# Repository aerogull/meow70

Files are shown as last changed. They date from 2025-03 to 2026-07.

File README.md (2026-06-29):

# Meow70
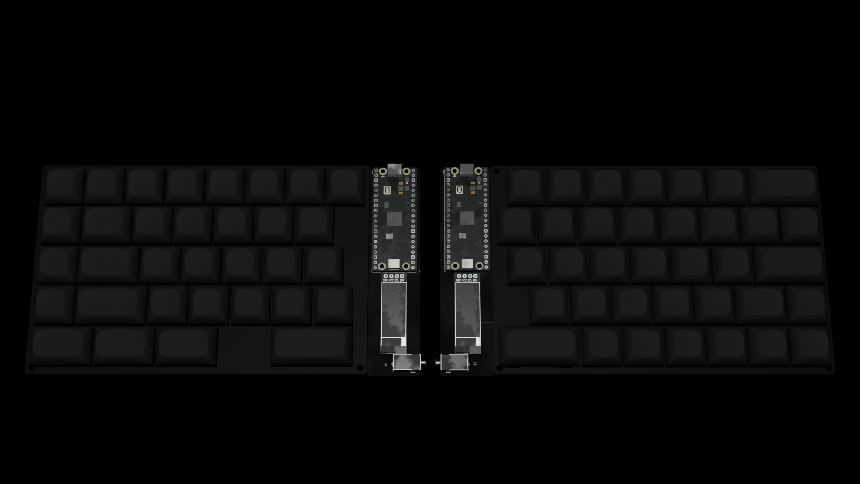
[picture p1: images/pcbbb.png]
render


## Building the Board
My idea started with how I wanted a split keyboard that wasn't ortholinear or ergo. So, I took a picture of my Keychron K6 Pro, and designed a split keyboard off of it. It runs on 2 Raspberry Pi Picos (or drop in replacements) with a simple, open case design and qmk firmware.\
This was a pretty difficult build, I ended up redoing the routing and placement several times, going from a staggered edge with the controllers mounted underneath, to what I have today. The most difficult part was doing the render of the keyboard (which is still a WIP, this is just temporary). My KICAD always gave me destroyed meshes that would take hours to import into any software. Once I finally got something imported, it took me 2 days of constantly doing little things and saving my work before blender crashed. The final render took over 8 minutes to finish, so it was quite an undertaking getting it to work.

## Bill of Materials
* 1x set of pcbs
* 2x Raspberry Pi Pico H
* 69x Kailh Hotswap Sockets (MX Style)
* 69x 1N4148 Diodes
* 69x MX-Style Switches
* 4x Plate-Mounted Stabilizers
* 2x 0.91" I2C PCB-Mounted OLED Displays
* 2x TRRS Audio Jack Connectors
* 8x M3 Screws
* 8x M3 Heatset Inserts

## More Photos
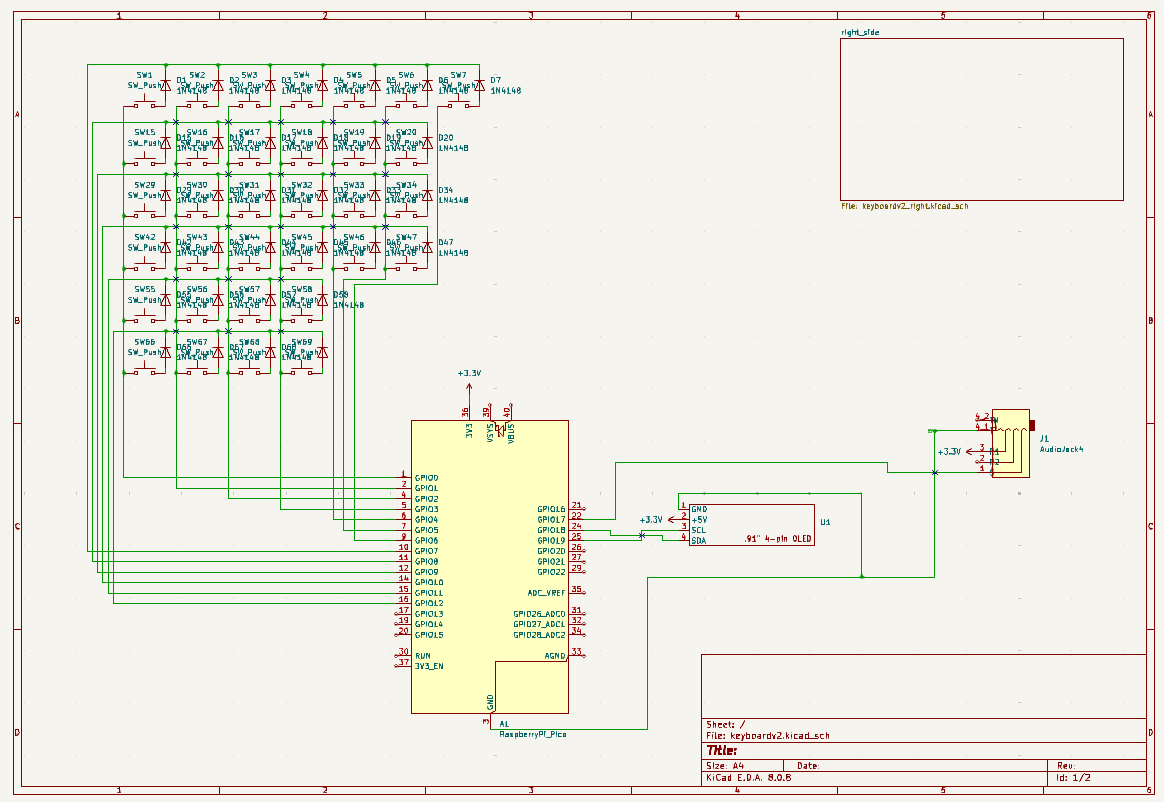
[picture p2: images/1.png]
schematic

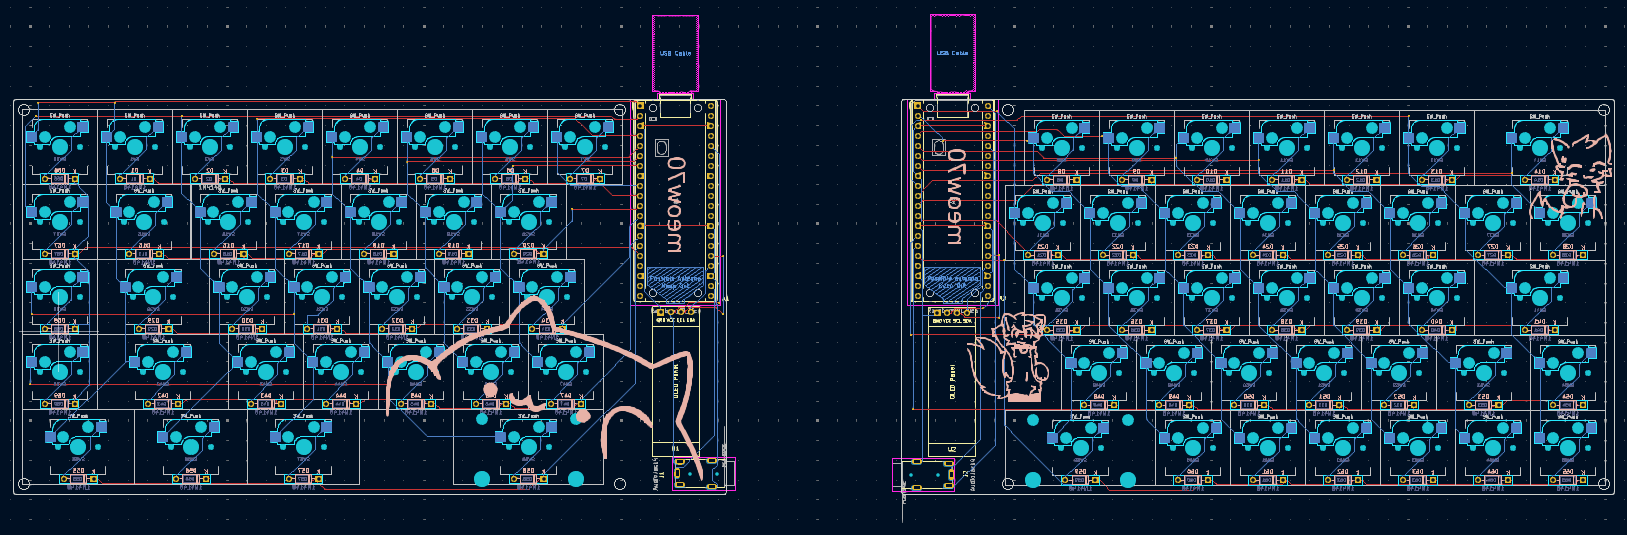
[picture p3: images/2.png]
pcb

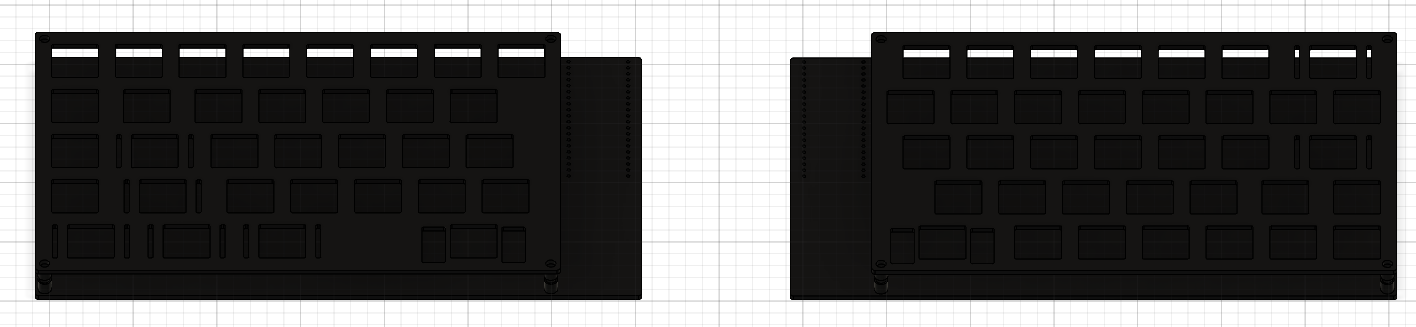
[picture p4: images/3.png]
case


## KICAD BOM (with prices for what I used)
|Quantity|Item|Designation|Price Each|Total Price + Shipping|Link|
|----|----|----|----|----|----|
|69|"MX-Hotswap"|"SW_Push"|$0.138|$9.65|[here](https://www.aliexpress.us/item/3256807039037559.html)|
|2|"RaspberryPi_Pico_Common_THT_wModel"|"RaspberryPi_Pico"|$4|Provided by HackClub HQ!||
|2|"SSD1306-0.91-OLED-4pin-128x32"|"~"|$1.845|$3.69|[here](https://www.aliexpress.us/item/3256805967573053.html)|
|2|"TENSILITY_54-00174" (PJ-332)|"AudioJack4"|$0.234|$2.34|[here](https://www.aliexpress.us/item/3256807580272301.html)|
|69|"D_DO-35_SOD27_P7.62mm_Horizontal"|"1N4148"|$0.0174|$1.74|[here](https://www.aliexpress.us/item/3256806058794623.html)|
|69|MX Mechanical Switches|Gateron G Pro 3.0 Silvers|$0.345|$50.11|[here](https://www.gateron.co/products/gateron-g-pro-3-0-switch-set?variant=40479583043673)
|69|Keycaps|3D Printed (Cherry or DSA)|Printing Legion||[this](https://github.com/rsheldiii/KeyV2) or [this](https://github.com/anhthang/dsa-keycap)|
|8|Heatset Inserts|97164A112|$0.0574|$5.74|[here](https://www.aliexpress.us/item/3256805603102147.html)|
|4|Stabilizers|Gateron 2u Stabs|$2.547|$15.28|[here](https://www.aliexpress.us/item/3256805212136654.html)|
|1|TRRS Cable|Random Aliexpress Coiled TRRS Cable|$6.94|$6.94|[here](https://www.aliexpress.us/item/3256806811164725.html)|
|1|Full Case|4 Parts Split Up for Printing|Self or Printing Legion||[here](https://github.com/aerogull/meow70/tree/main/prod)|
|8|Screws|3mm 0.5x16mm|$0.345|$2.76|[here](https://www.lowes.com/pd/Hillman-3mm-0-5-x-16mm-Allen-Drive-Cap-Screws-4-Count/50088880)|
|5|Sets of PCBs|JLCPCB|$20.70 (for 5)|$55.95|[here](https://cart.jlcpcb.com/quote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)|

[link to step model of completed board](https://hc-cdn.hel1.your-objectstorage.com/s/v3/b98df7d8c57167f14ca20340c5cecc1c217099e2_full_assembly_para.step)

## Completed Build!
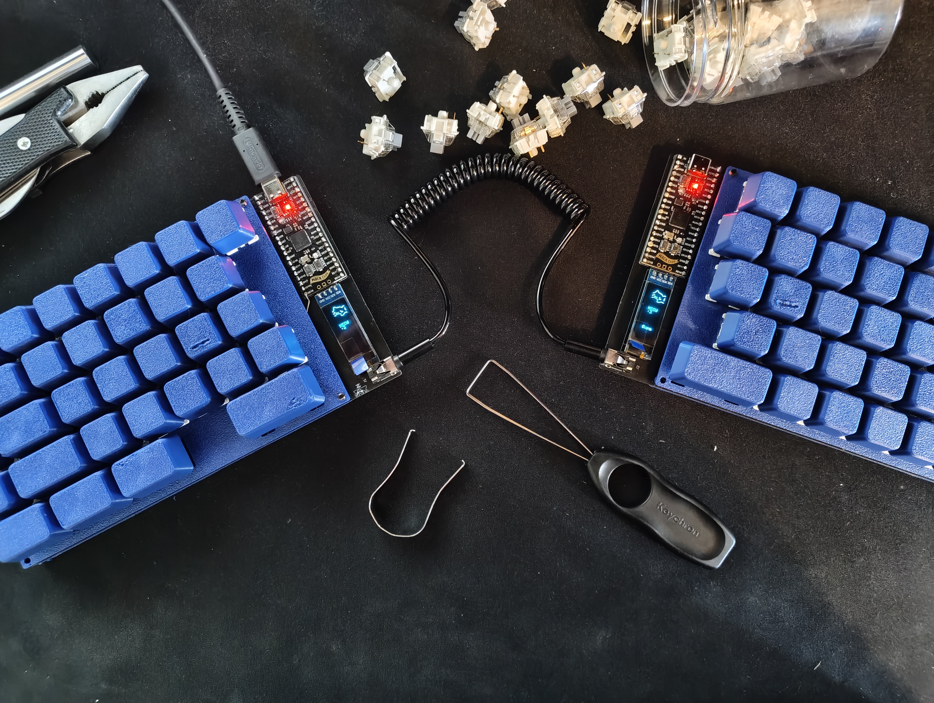
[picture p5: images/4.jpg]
build


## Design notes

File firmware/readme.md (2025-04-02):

# meow70

meow70

*A short description of the keyboard/project*

* Keyboard Maintainer: [aerogull](https://github.com/aerogull)
* Hardware Supported: the meow70 project
* Hardware Availability: *Links to where you can find this hardware*

Make example for this keyboard (after setting up your build environment):

    make meow70:default

Flashing example for this keyboard:

    make meow70:default:flash

See the [build environment setup](https://docs.qmk.fm/#/getting_started_build_tools) and the [make instructions](https://docs.qmk.fm/#/getting_started_make_guide) for more information. Brand new to QMK? Start with our [Complete Newbs Guide](https://docs.qmk.fm/#/newbs).

## Bootloader

Enter the bootloader in 3 ways:

* **Bootmagic reset**: Hold down the key at (0,0) in the matrix (usually the top left key or Escape) and plug in the keyboard
* **Physical reset button**: Briefly press the button on the back of the PCB - some may have pads you must short instead
* **Keycode in layout**: Press the key mapped to `QK_BOOT` if it is available

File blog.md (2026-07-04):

This a split keyboard that maintains most of the traditional layout of a standard keyboard.

69 total keys (nice)

4 programmable buttons (hardware macros :3)

2 layer switch buttons for even more keys (mmmmm function row)

USB-C connectivity (orph picos my beloved)

Dynamic master/slave (double the connectivity) 

TRRS cable connections (very sproingey)

2 128x32 OLED displays (2xBongo Cats not included)

Built in QMK (low latency for all the gamin)

VIA support (yk, unofficially)

Simple pcb shape (for making many many cases)

Hotswap keys (i'm thinking linears today, tactiles tomorrow)

Preconfigured out-of-the-box (some eeprom flashing required)

Everything was done by me, @aerogull.

Schematic:
    In the schematic, I set up the basics for how the keyboard functions, outlining serial communication between the halves, setting up matricies, and i2c communication for the displays. Each key also has it's own diode to prevent ghost taps and other crosstalk. I chose to use a pair of raspberry picos because of the amount of copycat footprints that could be used for drop in replacement boards.

PCB Design:
    This was where the layout really mattered. I wanted to copy my existing keyboard, a keychron 60 percent, but make it split for easier transport and travel use. The macro keys were placed on the sides to help mirror the shape of the keyboard halves, allowing for more uniform cases and designs. 

Case:
    I went with a really simple and open layout for 2 reasons, I like the sound better, and I did not have an easy way to prototype test tolerences and fit. It was originally designed to be used with heatset inserts, but it ended up being easier to drive the screws directly into the plastic. The plate was made with ai03 plate-gen, but the mounts for the stabs are the wrong kind so I had to dremel away some material to make them fit.

Firmware:
    QMK, pretty simple design with all the display hardcoded and eeprom flashing so you can't mess up where you plug the cord in. This firmware was developed in about 2 days or work, split across several years, so it went through some drastic changes. NKRO is enabled by default, and has unofficial via support included.

Render:
    Yay, blender! This was a lot of work trying to figure out why my mesh was in the GBs and why everything was a blog, but I think it turned out pretty good.

Build:
    I uh, didn't have any microcontroller headers, and broke one of the hotswap sockets that I only had one spare for so, it went about as good as it could go. It took about 9 hours of work to put it all together and get firmware tested and bug fixed.

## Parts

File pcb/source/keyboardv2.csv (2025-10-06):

Id | Designator | Footprint | Quantity | Designation | Supplier and ref
1 | SW17,SW20,SW24,SW3,SW67,SW47,SW49,SW2,SW62,SW52,SW44,SW11,SW40,SW9,SW1,SW64,SW50,SW39,SW51,SW60,SW34,SW36,SW37,SW38,SW10,SW28,SW16,SW35,SW19,SW32,SW27,SW7,SW21,SW68,SW66,SW25,SW45,SW69,SW23,SW26,SW13,SW65,SW22,SW8,SW54,SW63,SW18,SW5,SW46,SW43,SW30,SW61,SW31,SW4,SW6,SW33,SW48,SW12 | MX-Hotswap-1U | 58 | SW_Push
2 | SW53,SW15 | MX-Hotswap-1.25U | 2 | SW_Push
3 | A1,A3 | RaspberryPi_Pico_Common_THT_wModel | 2 | RaspberryPi_Pico
4 | SW42,SW14,SW41 | MX-Hotswap-1.75U | 3 | SW_Push
5 | U2,U1 | SSD1306-0.91-OLED-4pin-128x32 | 2 | ~
6 | SW56,SW29,SW57,SW55 | MX-Hotswap-1.5U | 4 | SW_Push
7 | J2,J1 | TENSILITY_54-00174 | 2 | AudioJack4
8 | SW59,SW58 | MX-Hotswap-2U | 2 | SW_Push
9 | D44,D54,D62,D55,D63,D69,D28,D52,D53,D45,D17,D9,D35,D12,D4,D31,D43,D18,D50,D26,D47,D33,D23,D39,D24,D7,D27,D48,D49,D58,D13,D32,D19,D57,D64,D30,D38,D8,D37,D68,D66,D20,D29,D60,D36,D15,D21,D2,D1,D10,D11,D61,D40,D56,D6,D25,D59,D34,D46,D16,D22,D67,D65,D42,D3,D51,D41,D5,D14 | D_DO-35_SOD27_P7.62mm_Horizontal | 69 | 1N4148

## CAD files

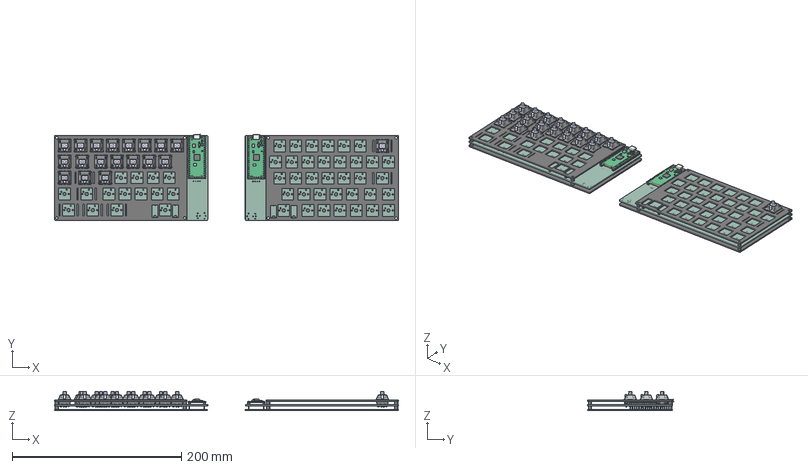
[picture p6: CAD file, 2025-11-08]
models/meow70_case.step
406.6 x 101.7 x 22.8 mm
RaspberryPi_Pico_AddedHeaders_Compound x 2
MX °´¼ü_¨¹_¡§1 x 4
D_DO-35_SOD27_P7.62mm_Horizontal_1 x 69
keyboardv2_PCB_1
keyboardv2_PCB_2
case_left
plate-2025-02-23T15_52_50.940Z v1
MX Öá °´¼ü¡ä_¨¹ ___¡§1_1 x 18
MX Öá ÖáÌå¨¢¨¬ _¡§¡é¡§___1 x 18
MXÖá ÎÞÃ±LEDLEDLED_1 x 18
MXÖá ÖáÌå µ×²¿ ¦Ì¡ Á2__Ä¬ÈÏ_¨¢2____¨¨__1 x 18
Õë½Å___Ä¬ÈÏ__¨¨ __1 x 18
MX Öá °´¼ü¡ä_¨¹ ___¡§1
MX Öá ÖáÌå¨¢¨¬ _¡§¡é¡§__
MXÖá ÎÞÃ±LEDLEDLED
MXÖá ÖáÌå µ×²¿ ¦Ì¡ Á2__Ä¬ÈÏ_¨¢2____¨¨_
Õë½Å___Ä¬ÈÏ__¨¨ _
plate-2025-02-23T16_18_41.060Z v1
case_top_left
case_top_right
case_bottom_left
case_bottom_right

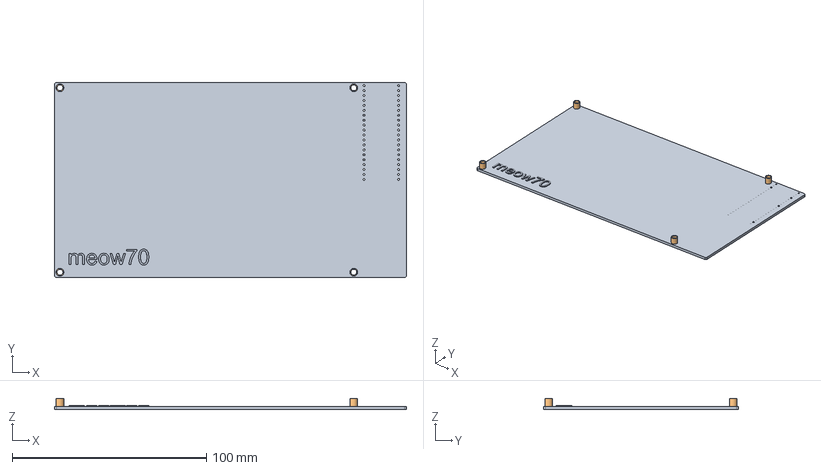
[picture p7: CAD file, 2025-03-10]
prod/case_bottom_left v3.step
181.2 x 100.5 x 5.60 mm

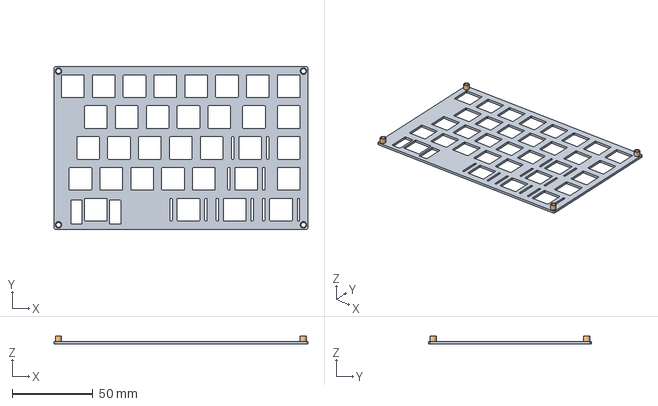
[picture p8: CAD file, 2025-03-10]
prod/case_top_left v2.step
156.8 x 100.5 x 5.10 mm

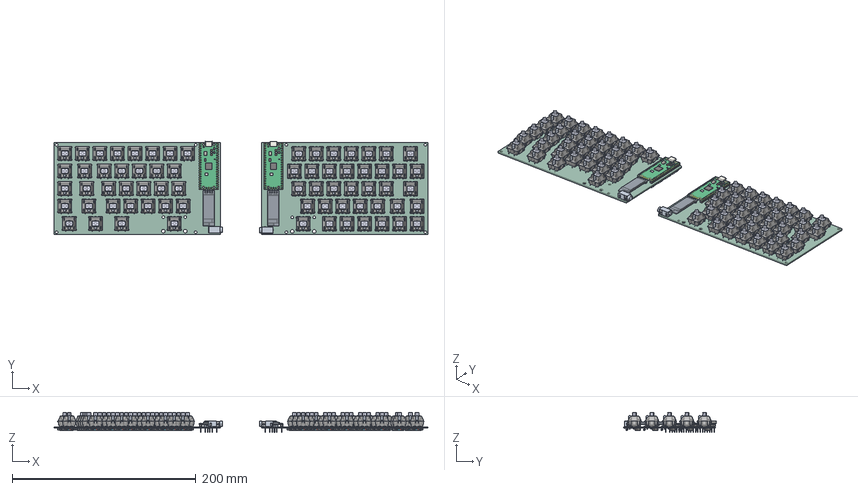
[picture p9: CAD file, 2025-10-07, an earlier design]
pcb/old/keyboardv2.step
406.7 x 101.6 x 22.1 mm
Kailh Socket v12 x 69
MX °´¼ü_¨¹_¡§1 x 69
RaspberryPi_Pico_AddedHeaders_Compound x 2
OLED_0.91_128x32 x 2
D_DO-35_SOD27_P7.62mm_Horizontal x 69
keyboardv2_PCB_1
keyboardv2_PCB_2

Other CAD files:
prod/case_bottom_right v2.step
prod/case_top_right v2.step

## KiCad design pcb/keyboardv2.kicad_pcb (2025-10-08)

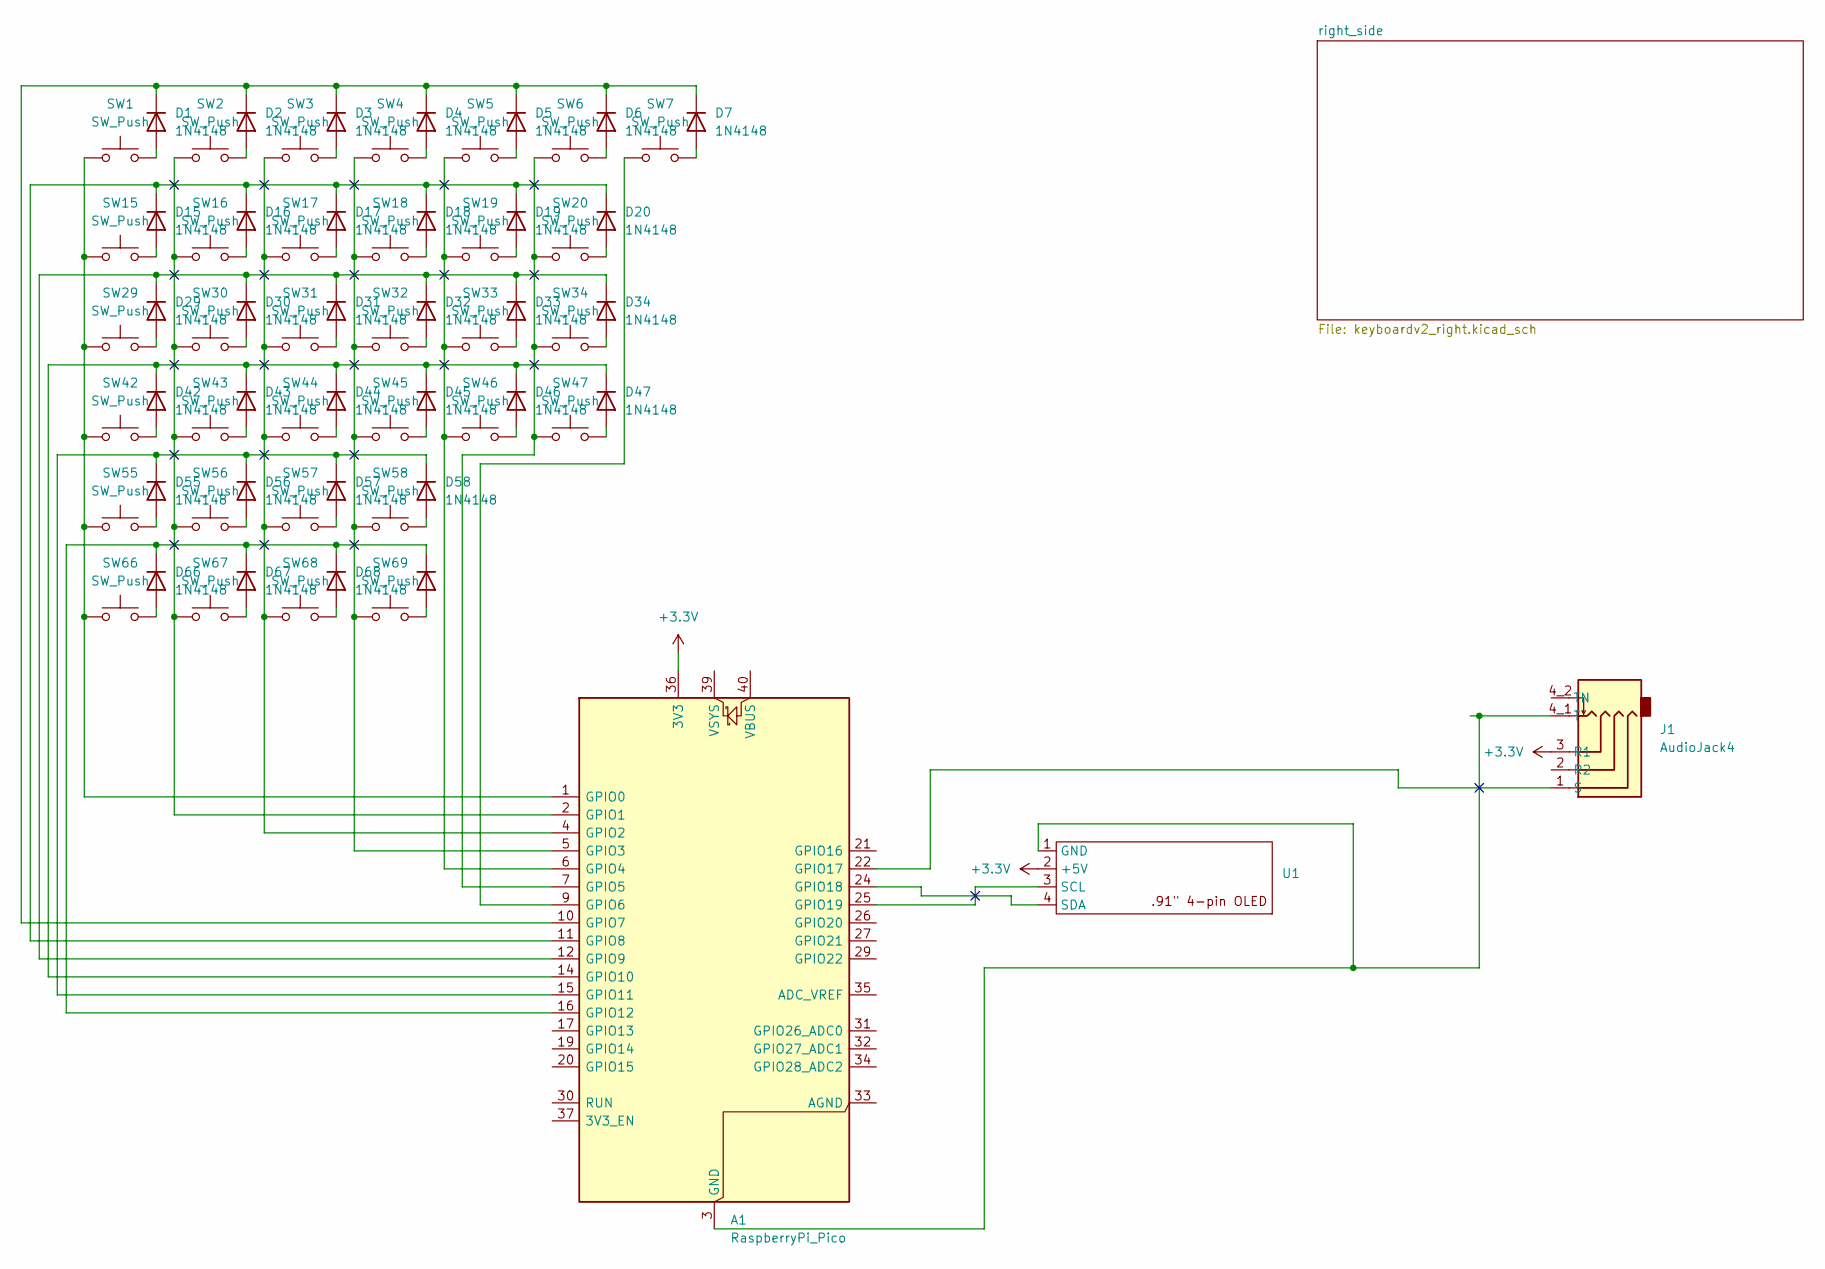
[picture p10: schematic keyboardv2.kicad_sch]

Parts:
A1: RaspberryPi_Pico; RaspberryPi_Pico_Common_THT
D1, D2, D3, D4, D5, D6, D7, D15, D16, D17, D18, D19, D20, D29, D30, D31, D32, D33, D34, D42, D43, D44, D45, D46, D47, D55, D56, D57, D58, D66, D67, D68, D69: 1N4148; D_DO-35_SOD27_P7.62mm_Horizontal
J1: AudioJack4; TENSILITY_54-00174
SW1, SW2, SW3, SW4, SW5, SW6, SW7, SW16, SW17, SW18, SW19, SW20, SW30, SW31, SW32, SW33, SW34, SW43, SW44, SW45, SW46, SW47, SW66, SW67, SW68, SW69: SW_Push; MX-Hotswap-1U
SW15: SW_Push; MX-Hotswap-1.25U
SW29, SW55, SW56, SW57: SW_Push; MX-Hotswap-1.5U
SW42: SW_Push; MX-Hotswap-1.75U
SW58: SW_Push; MX-Hotswap-2U
U1: SSD1306-0.91-OLED-4pin-128x32

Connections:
+3.3V: A1.36 (3V3), J1.3 (R1), U1.2 (+5V)
unnamed: A1.1 (GPIO0), SW1.1, SW15.1, SW29.1, SW42.1, SW55.1, SW66.1
unnamed: A1.2 (GPIO1), SW2.1, SW16.1, SW30.1, SW43.1, SW56.1, SW67.1
unnamed: A1.4 (GPIO2), SW3.1, SW17.1, SW31.1, SW44.1, SW57.1, SW68.1
unnamed: A1.5 (GPIO3), SW4.1, SW18.1, SW32.1, SW45.1, SW58.1, SW69.1
unnamed: A1.6 (GPIO4), SW5.1, SW19.1, SW33.1, SW46.1
unnamed: A1.7 (GPIO5), SW6.1, SW20.1, SW34.1, SW47.1
unnamed: A1.9 (GPIO6), SW7.1
unnamed: A1.10 (GPIO7), D1.1 (K), D2.1 (K), D3.1 (K), D4.1 (K), D5.1 (K), D6.1 (K), D7.1 (K)
unnamed: A1.11 (GPIO8), D15.1 (K), D16.1 (K), D17.1 (K), D18.1 (K), D19.1 (K), D20.1 (K)
unnamed: A1.12 (GPIO9), D29.1 (K), D30.1 (K), D31.1 (K), D32.1 (K), D33.1 (K), D34.1 (K)
unnamed: A1.14 (GPIO10), D42.1 (K), D43.1 (K), D44.1 (K), D45.1 (K), D46.1 (K), D47.1 (K)
unnamed: A1.15 (GPIO11), D55.1 (K), D56.1 (K), D57.1 (K), D58.1 (K)
unnamed: A1.16 (GPIO12), D66.1 (K), D67.1 (K), D68.1 (K), D69.1 (K)
unnamed: A1.22 (GPIO17), J1.1 (S)
unnamed: A1.24 (GPIO18), U1.4 (SDA)
unnamed: A1.25 (GPIO19), U1.3 (SCL)
unnamed: D1.2 (A), SW1.2
unnamed: D2.2 (A), SW2.2
unnamed: D3.2 (A), SW3.2
unnamed: D4.2 (A), SW4.2
unnamed: D5.2 (A), SW5.2
unnamed: D6.2 (A), SW6.2
unnamed: D7.2 (A), SW7.2
unnamed: D15.2 (A), SW15.2
unnamed: D16.2 (A), SW16.2
unnamed: D17.2 (A), SW17.2
unnamed: D18.2 (A), SW18.2
unnamed: D19.2 (A), SW19.2
unnamed: D20.2 (A), SW20.2
unnamed: D29.2 (A), SW29.2
unnamed: D30.2 (A), SW30.2
unnamed: D31.2 (A), SW31.2
unnamed: D32.2 (A), SW32.2
unnamed: D33.2 (A), SW33.2
unnamed: D34.2 (A), SW34.2
unnamed: D42.2 (A), SW42.2
unnamed: D43.2 (A), SW43.2
unnamed: D44.2 (A), SW44.2
unnamed: D45.2 (A), SW45.2
unnamed: D46.2 (A), SW46.2
unnamed: D47.2 (A), SW47.2
unnamed: D55.2 (A), SW55.2
unnamed: D56.2 (A), SW56.2
unnamed: D57.2 (A), SW57.2
unnamed: D58.2 (A), SW58.2
unnamed: D66.2 (A), SW66.2
unnamed: D67.2 (A), SW67.2
unnamed: D68.2 (A), SW68.2
unnamed: D69.2 (A), SW69.2
unnamed: A1.3 (GND), A1.8 (GND), A1.13 (GND), A1.18 (GND), A1.23 (GND), A1.28 (GND), A1.38 (GND), J1.4_1 (T), U1.1 (GND)

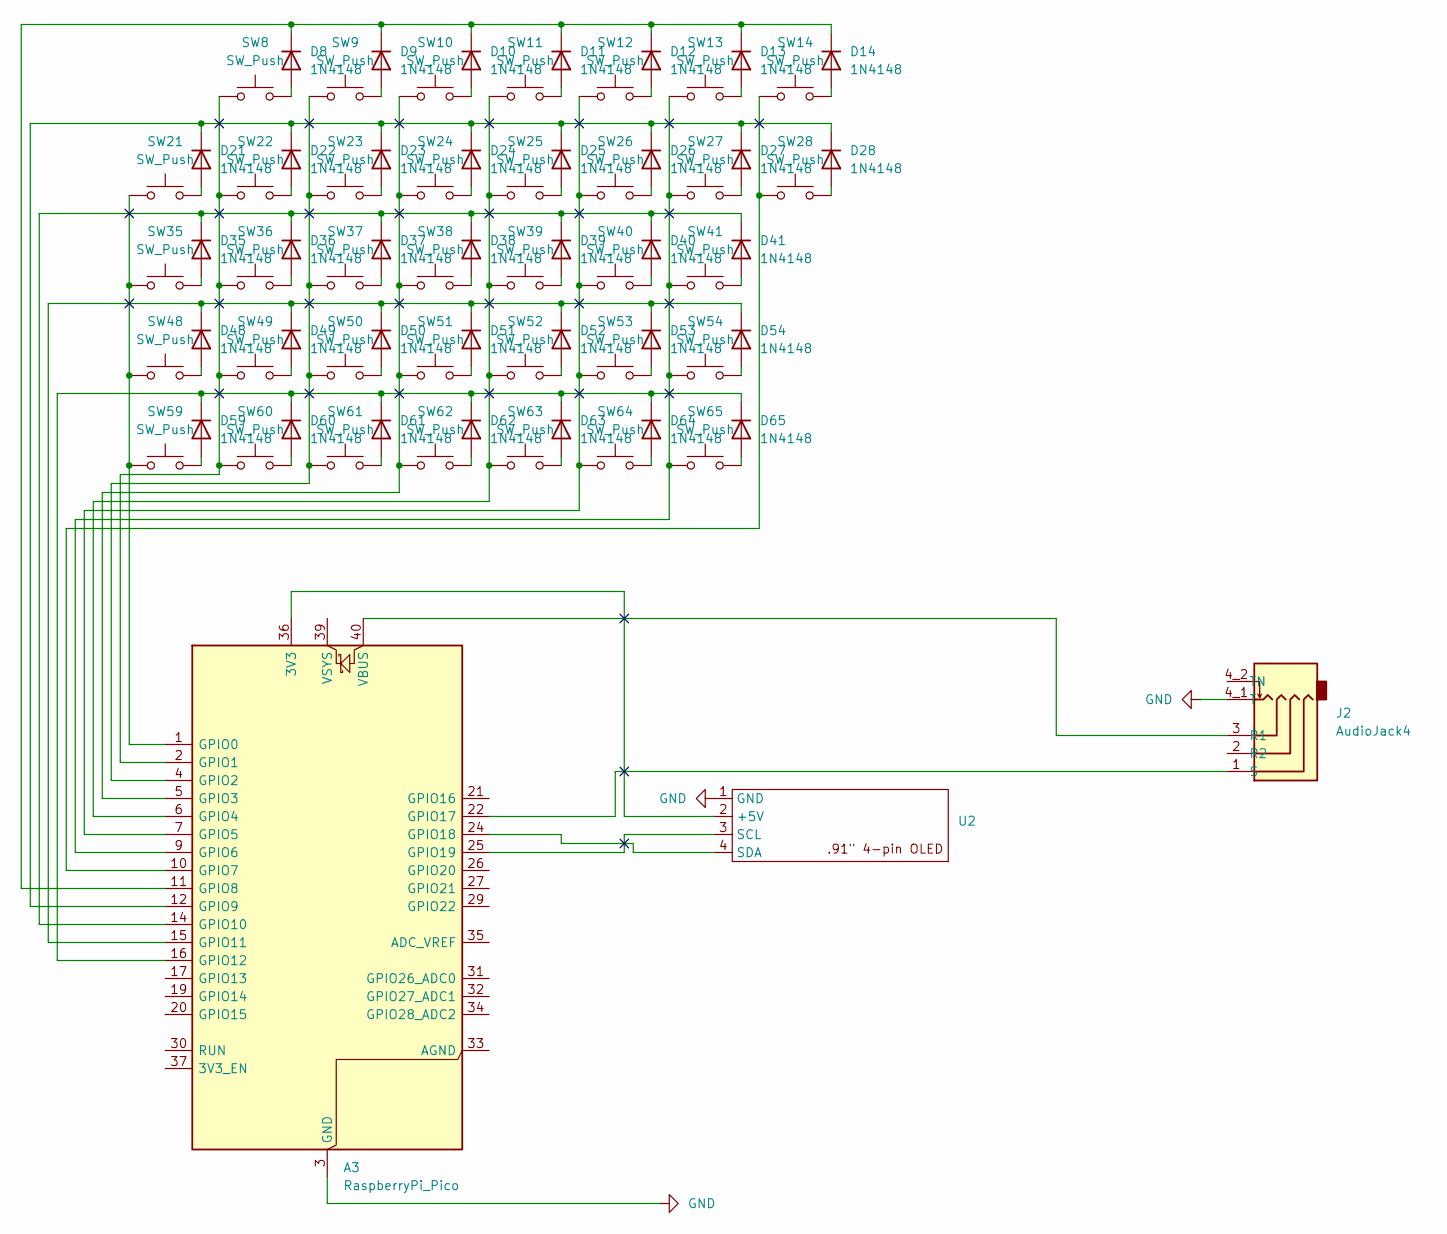
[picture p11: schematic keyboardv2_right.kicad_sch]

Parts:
A3: RaspberryPi_Pico; RaspberryPi_Pico_Common_THT
D8, D9, D10, D11, D12, D13, D14, D21, D22, D23, D24, D25, D26, D27, D28, D35, D36, D37, D38, D39, D40, D41, D48, D49, D50, D51, D52, D53, D54, D59, D60, D61, D62, D63, D64, D65: 1N4148; D_DO-35_SOD27_P7.62mm_Horizontal
J2: AudioJack4; TENSILITY_54-00174
SW8, SW9, SW10, SW11, SW12, SW13, SW21, SW22, SW23, SW24, SW25, SW26, SW27, SW28, SW35, SW36, SW37, SW38, SW39, SW40, SW48, SW49, SW50, SW51, SW52, SW54, SW60, SW61, SW62, SW63, SW64, SW65: SW_Push; MX-Hotswap-1U
SW14, SW41: SW_Push; MX-Hotswap-1.75U
SW53: SW_Push; MX-Hotswap-1.25U
SW59: SW_Push; MX-Hotswap-2U
U2: SSD1306-0.91-OLED-4pin-128x32

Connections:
GND: A3.3 (GND), A3.8 (GND), A3.13 (GND), A3.18 (GND), A3.23 (GND), A3.28 (GND), A3.38 (GND), J2.4_1 (T), U2.1 (GND)
unnamed: A3.36 (3V3), U2.2 (+5V)
unnamed: A3.1 (GPIO0), SW21.1, SW35.1, SW48.1, SW59.1
unnamed: A3.2 (GPIO1), SW8.1, SW22.1, SW36.1, SW49.1, SW60.1
unnamed: A3.4 (GPIO2), SW9.1, SW23.1, SW37.1, SW50.1, SW61.1
unnamed: A3.5 (GPIO3), SW10.1, SW24.1, SW38.1, SW51.1, SW62.1
unnamed: A3.6 (GPIO4), SW11.1, SW25.1, SW39.1, SW52.1, SW63.1
unnamed: A3.7 (GPIO5), SW12.1, SW26.1, SW40.1, SW53.1, SW64.1
unnamed: A3.9 (GPIO6), SW13.1, SW27.1, SW41.1, SW54.1, SW65.1
unnamed: A3.10 (GPIO7), SW14.1, SW28.1
unnamed: A3.11 (GPIO8), D8.1 (K), D9.1 (K), D10.1 (K), D11.1 (K), D12.1 (K), D13.1 (K), D14.1 (K)
unnamed: A3.12 (GPIO9), D21.1 (K), D22.1 (K), D23.1 (K), D24.1 (K), D25.1 (K), D26.1 (K), D27.1 (K), D28.1 (K)
unnamed: A3.14 (GPIO10), D35.1 (K), D36.1 (K), D37.1 (K), D38.1 (K), D39.1 (K), D40.1 (K), D41.1 (K)
unnamed: A3.15 (GPIO11), D48.1 (K), D49.1 (K), D50.1 (K), D51.1 (K), D52.1 (K), D53.1 (K), D54.1 (K)
unnamed: A3.16 (GPIO12), D59.1 (K), D60.1 (K), D61.1 (K), D62.1 (K), D63.1 (K), D64.1 (K), D65.1 (K)
unnamed: A3.22 (GPIO17), J2.1 (S)
unnamed: A3.24 (GPIO18), U2.4 (SDA)
unnamed: A3.25 (GPIO19), U2.3 (SCL)
unnamed: A3.40 (VBUS), J2.3 (R1)
unnamed: D8.2 (A), SW8.2
unnamed: D9.2 (A), SW9.2
unnamed: D10.2 (A), SW10.2
unnamed: D11.2 (A), SW11.2
unnamed: D12.2 (A), SW12.2
unnamed: D13.2 (A), SW13.2
unnamed: D14.2 (A), SW14.2
unnamed: D21.2 (A), SW21.2
unnamed: D22.2 (A), SW22.2
unnamed: D23.2 (A), SW23.2
unnamed: D24.2 (A), SW24.2
unnamed: D25.2 (A), SW25.2
unnamed: D26.2 (A), SW26.2
unnamed: D27.2 (A), SW27.2
unnamed: D28.2 (A), SW28.2
unnamed: D35.2 (A), SW35.2
unnamed: D36.2 (A), SW36.2
unnamed: D37.2 (A), SW37.2
unnamed: D38.2 (A), SW38.2
unnamed: D39.2 (A), SW39.2
unnamed: D40.2 (A), SW40.2
unnamed: D41.2 (A), SW41.2
unnamed: D48.2 (A), SW48.2
unnamed: D49.2 (A), SW49.2
unnamed: D50.2 (A), SW50.2
unnamed: D51.2 (A), SW51.2
unnamed: D52.2 (A), SW52.2
unnamed: D53.2 (A), SW53.2
unnamed: D54.2 (A), SW54.2
unnamed: D59.2 (A), SW59.2
unnamed: D60.2 (A), SW60.2
unnamed: D61.2 (A), SW61.2
unnamed: D62.2 (A), SW62.2
unnamed: D63.2 (A), SW63.2
unnamed: D64.2 (A), SW64.2
unnamed: D65.2 (A), SW65.2

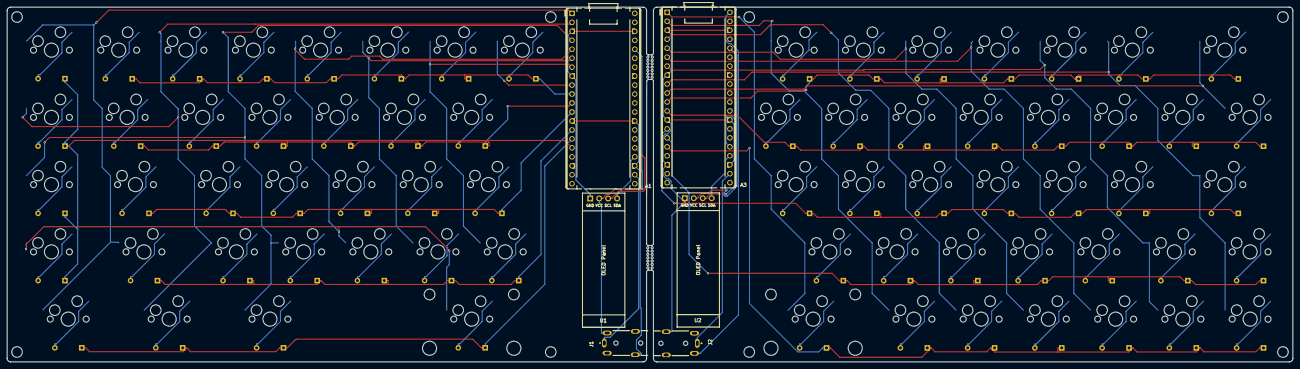
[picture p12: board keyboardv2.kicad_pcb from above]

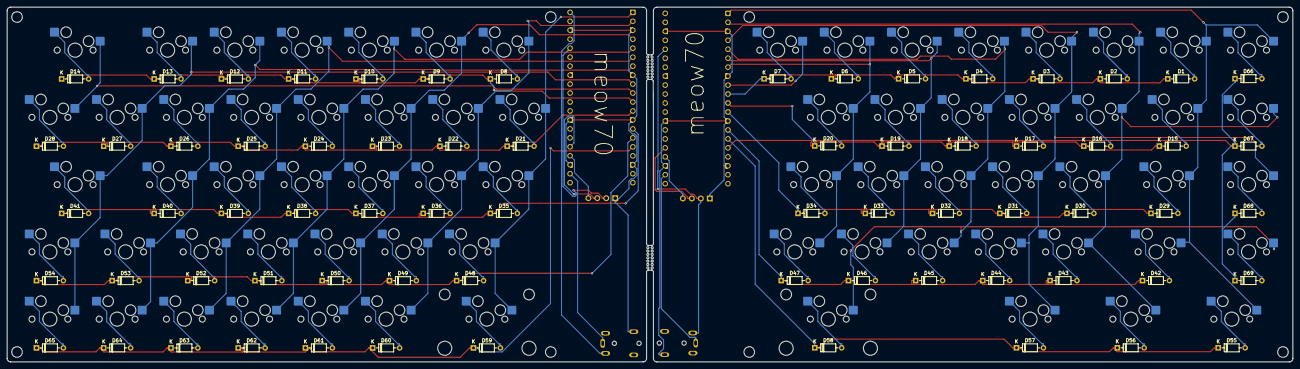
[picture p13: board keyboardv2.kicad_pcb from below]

Board: 2 copper layers, 364.2 x 100.5 mm, 144 parts (69 on the bottom side), 106 nets.

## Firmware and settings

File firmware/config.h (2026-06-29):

#define SERIAL_PIO_USE_PIO0
#define SSD1306_NUM_I2C_DEVICES 1
#define SSD1306_I2C_SDA_PIN GP18
#define SSD1306_I2C_SCL_PIN GP19
#define OLED_SDA_PIN GP18
#define OLED_SCL_PIN GP19
#define I2C1_SDA_PIN GP18
#define I2C1_SCL_PIN GP19

#define OLED_TIMEOUT 0
#define FORCE_NKRO
#define DEBOUNCE 3

#define EE_HANDS

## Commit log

2025-02-13 init for testing
    [keyboardv2.kicad_pcb, keyboardv2.kicad_sch, keyboardv2_right.kicad_sch]
2025-03-09 finished v2 of keeb
    [case_bottom_left v2.obj, case_bottom_right v2.obj, case_top_left v2.obj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]
2025-03-10 changed obj to step
    [case_bottom_left v2.obj, case_bottom_left v3.step, case_bottom_right v2.obj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]
2025-03-10 added pcb source
    [keyboardv2.1.dsn, keyboardv2.2.dsn, keyboardv2.dsn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]
2025-10-06 minor updates with bom added
    [keyboardv2.2.dsn, keyboardv2.csv, keyboardv2.kicad_pcb]
2025-10-06 minor bom updates
2025-10-06 minor bom updates v2
2025-10-06 minor bom updates v3
2025-10-07 bom changes and layout changes
    [case_bottom_left v3.step, case_bottom_right v2.step, case_top_left v2.step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]
2025-10-08 working on a full 3d model of the board
    [keyboardv2.kicad_pcb]
2025-10-09 take 3
    [full_assembly v1.step]
2025-10-09 updated gerbers
2025-10-09 updated bom with links and other goodies
2025-10-13 updated bom to include pcb
2025-10-17 updated prices in bom
2025-10-18 bom changes
2025-10-18 updated bom v2
2025-11-08 old model
    [full_assembly v1.step, meow70_case.step]
